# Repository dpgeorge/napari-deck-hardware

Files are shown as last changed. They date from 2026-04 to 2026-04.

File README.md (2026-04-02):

Napari Deck Hardware
====================

The Napari Deck is a custom keyboard-like USB HID input device with keys,
sliders, encoders and trackpads.  It is optimised for controlling [napari],
a multi-dimensional image viewer.

This repository contains the hardware design files needed to build a Napari
Deck: parts lists, 3D printed housing files and PCB design files.

Deck v1
-------

Napari Deck v1 is the first iteration of the housing and inputs (encoders, sliders,
buttons).  It is used to evaluate the inputs and the general layout of the deck.

It has the following inputs:
- mini trackball at the thumb position
- two keyboard switches
- two encoders
- iPod-like dial with encoder and five buttons
- mini joystick
- a slider (linear potentiometer)

Deck v2
-------

Napari Deck v2 is the second iteration of the housing and inputs, and is a fully
functional USB HID device that works with napari using `napari-deck-plugin`.

It has the following inputs:
- mini joystick at the thumb position for 3D rotation
- mini trackball at the thumb position for panning
- two encoders at the thumb position for rotation and zoom
- 16 keyboard switches
- three encoders for 3-axis slicing
- two sliders for opacity and brush size
- two sliders combined with a selection switch for four clipping planes

Deck mini
---------

Napari Deck Mini is a small device used to evaluate a mini trackpad and an encoder.
It is fully functional and works with napari.

It has the following inputs:
- mini trackpad
- encoder

Deck v3
-------

Napari Deck v3 is the third iteration of the housing and inputs.  It has a custom
PCB to simplify the construction, with a built-in STM32G0B1 microcontroller.

It has the following inputs:
- two mini trackpads at the thumb position for 2D panning and 3D rotation
- two encoders at the thumb position for zoom and 3D rotation
- 16 keyboard switches
- three encoders for 3-axis slicing
- two sliders for opacity and brush size
- two sliders combined with a 4-way selection switch for eight clipping planes

Deck v3 is currently a work-in-progress.

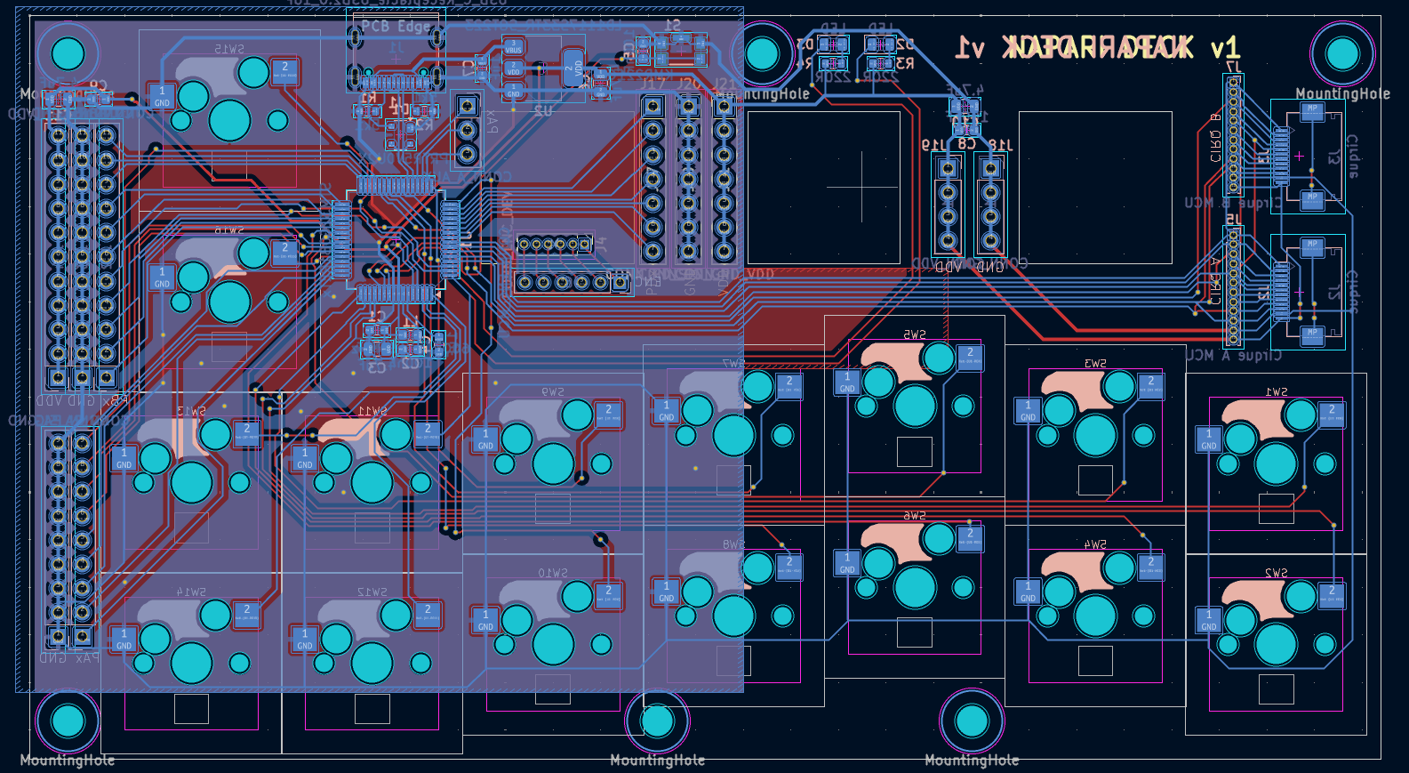
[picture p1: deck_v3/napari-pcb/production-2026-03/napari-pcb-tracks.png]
KiCad track layout for deck v3


[napari]: https://github.com/napari/napari

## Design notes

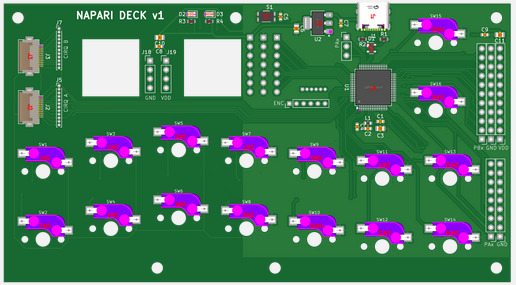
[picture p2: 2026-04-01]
deck_v3/napari-pcb/production-2026-03/napari-pcb-jlcpcb-model.jpg

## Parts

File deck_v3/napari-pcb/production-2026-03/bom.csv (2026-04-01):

Designator | Footprint | Quantity | Value | LCSC Part #
C1, C2, C5, C8, C9 | 0603 | 5 | 100nF | C14663
C10, C11, C3, C6 | 0805 | 4 | 4.7uF | C1779
C4, C7 | 0603 | 2 | 1uF | C15849
D1 | SOT-143 | 1 | PRTR5V0U2X | C2827688
D2 | 0805 | 1 | LED | C84256
D3 | 0805 | 1 | LED | C2297
J1 | USB_C_Receptacle_Palconn_UTC16-G | 1 | USB_C_Receptacle_USB2.0_16P | C165948
J2, J3 | Hirose_FH12-12S-0.5SH_1x12-1MP_P0.50mm_Horizontal | 2 | Cirque | C88360
L1 | 0603 | 1 | 600R @ 100MHz | C1002
R1, R2 | 0603 | 2 | 5k1 | C23186
R3, R4 | 0603 | 2 | 220R | C22962
S1 | SW_KMR221GLFS | 1 | KMR221GLFS | C72443
SW1, SW10, SW11, SW12, SW13, SW14, SW15, SW16, SW2, SW3, SW4, SW5, SW6, SW7, SW8, SW9 | keyswitch_cherrymx_hotswap_1u | 16 | SW_Push | C41430893
U1 | LQFP-64_10x10mm_P0.5mm | 1 | STM32G0B1RETx | C2829307
U2 | SOT-223-3_TabPin2 | 1 | LD1117S33TR_SOT223 | C435835

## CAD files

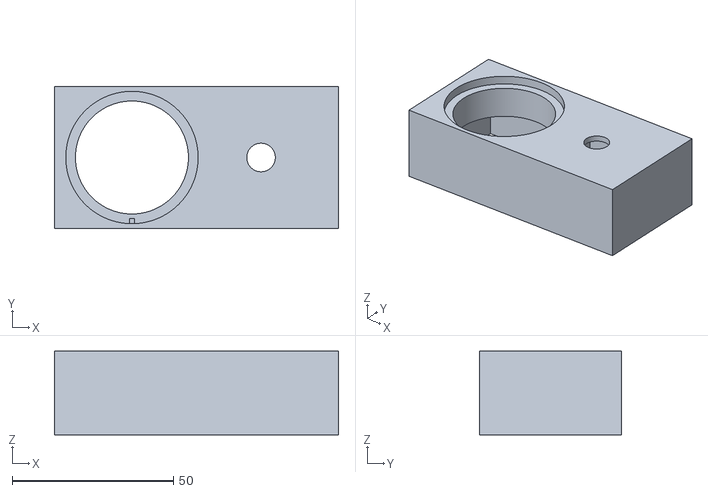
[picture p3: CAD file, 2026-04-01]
deck_mini/napari_mini.stl
88.0 x 44.0 x 26.0

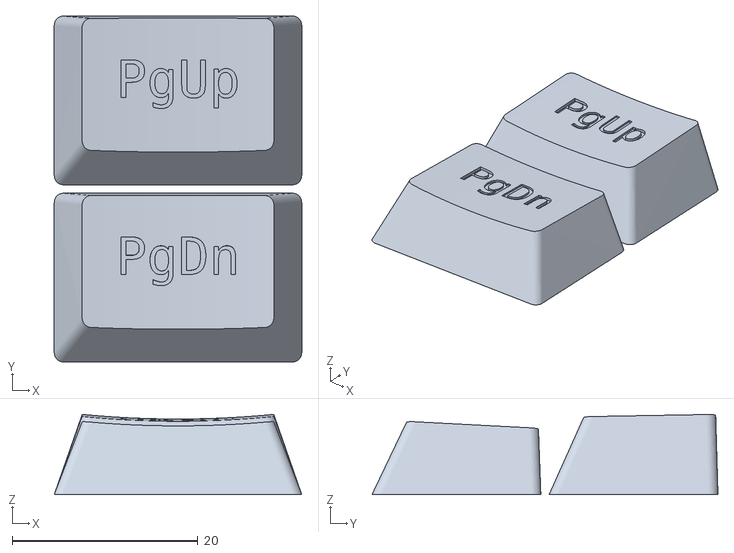
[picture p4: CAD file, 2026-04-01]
keycaps/pgup_pgdn_u1p444.stl
26.6 x 37.2 x 8.61

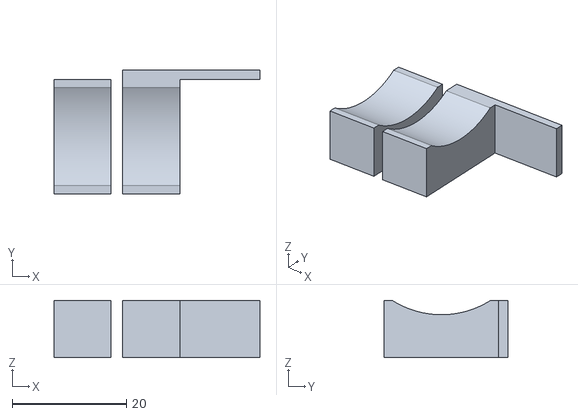
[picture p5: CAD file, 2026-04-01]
keycaps/keycaps_slider.stl
36.0 x 21.6 x 10.0

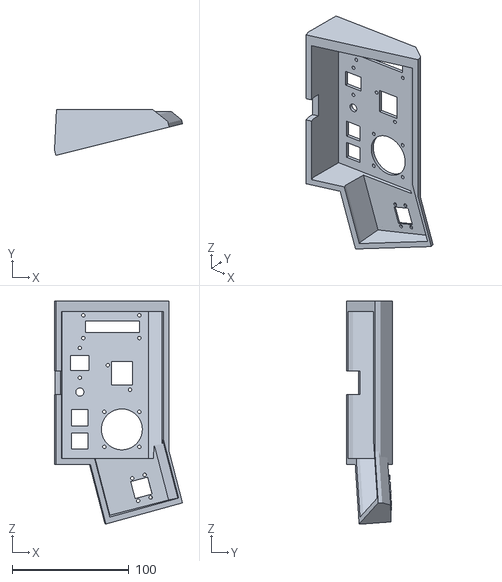
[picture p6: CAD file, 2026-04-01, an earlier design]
deck_v1/napari_v1.stl
109.7 x 39.3 x 191.1

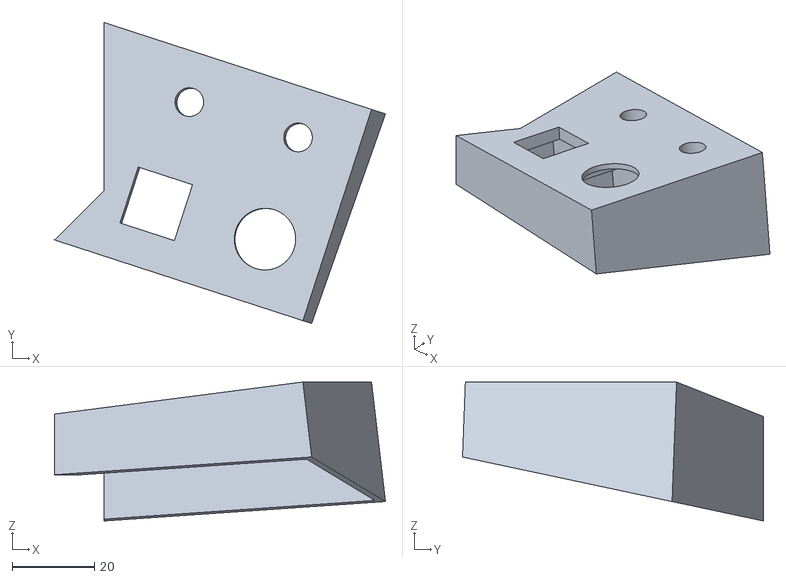
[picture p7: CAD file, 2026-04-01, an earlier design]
deck_v2/napari_v2_right.stl
80.5 x 73.2 x 33.8

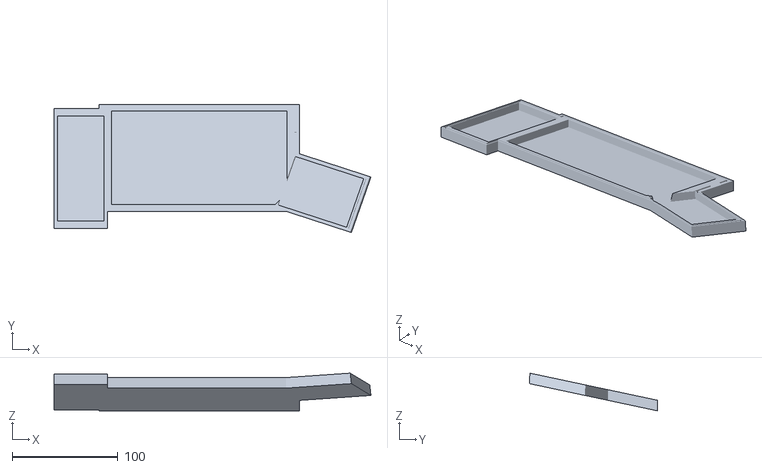
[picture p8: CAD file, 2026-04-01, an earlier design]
deck_v2/napari_v2_base_thick.stl
299.6 x 121.1 x 35.7

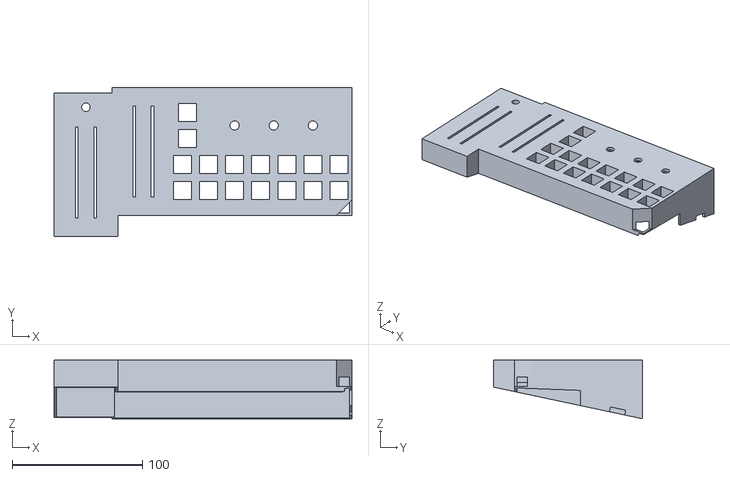
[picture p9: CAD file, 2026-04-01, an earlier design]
deck_v2/napari_v2_centre.stl
228.5 x 114.0 x 44.9

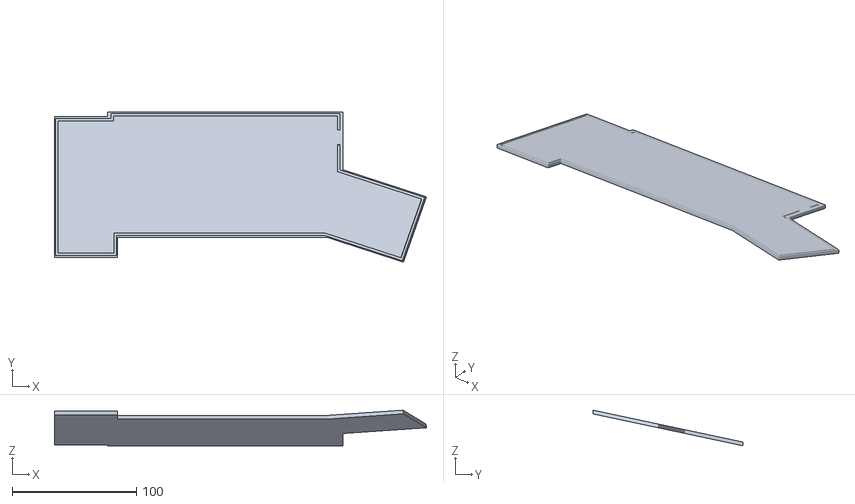
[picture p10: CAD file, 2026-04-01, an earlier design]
deck_v2/napari_v2_base_thin.stl
298.9 x 120.8 x 28.7

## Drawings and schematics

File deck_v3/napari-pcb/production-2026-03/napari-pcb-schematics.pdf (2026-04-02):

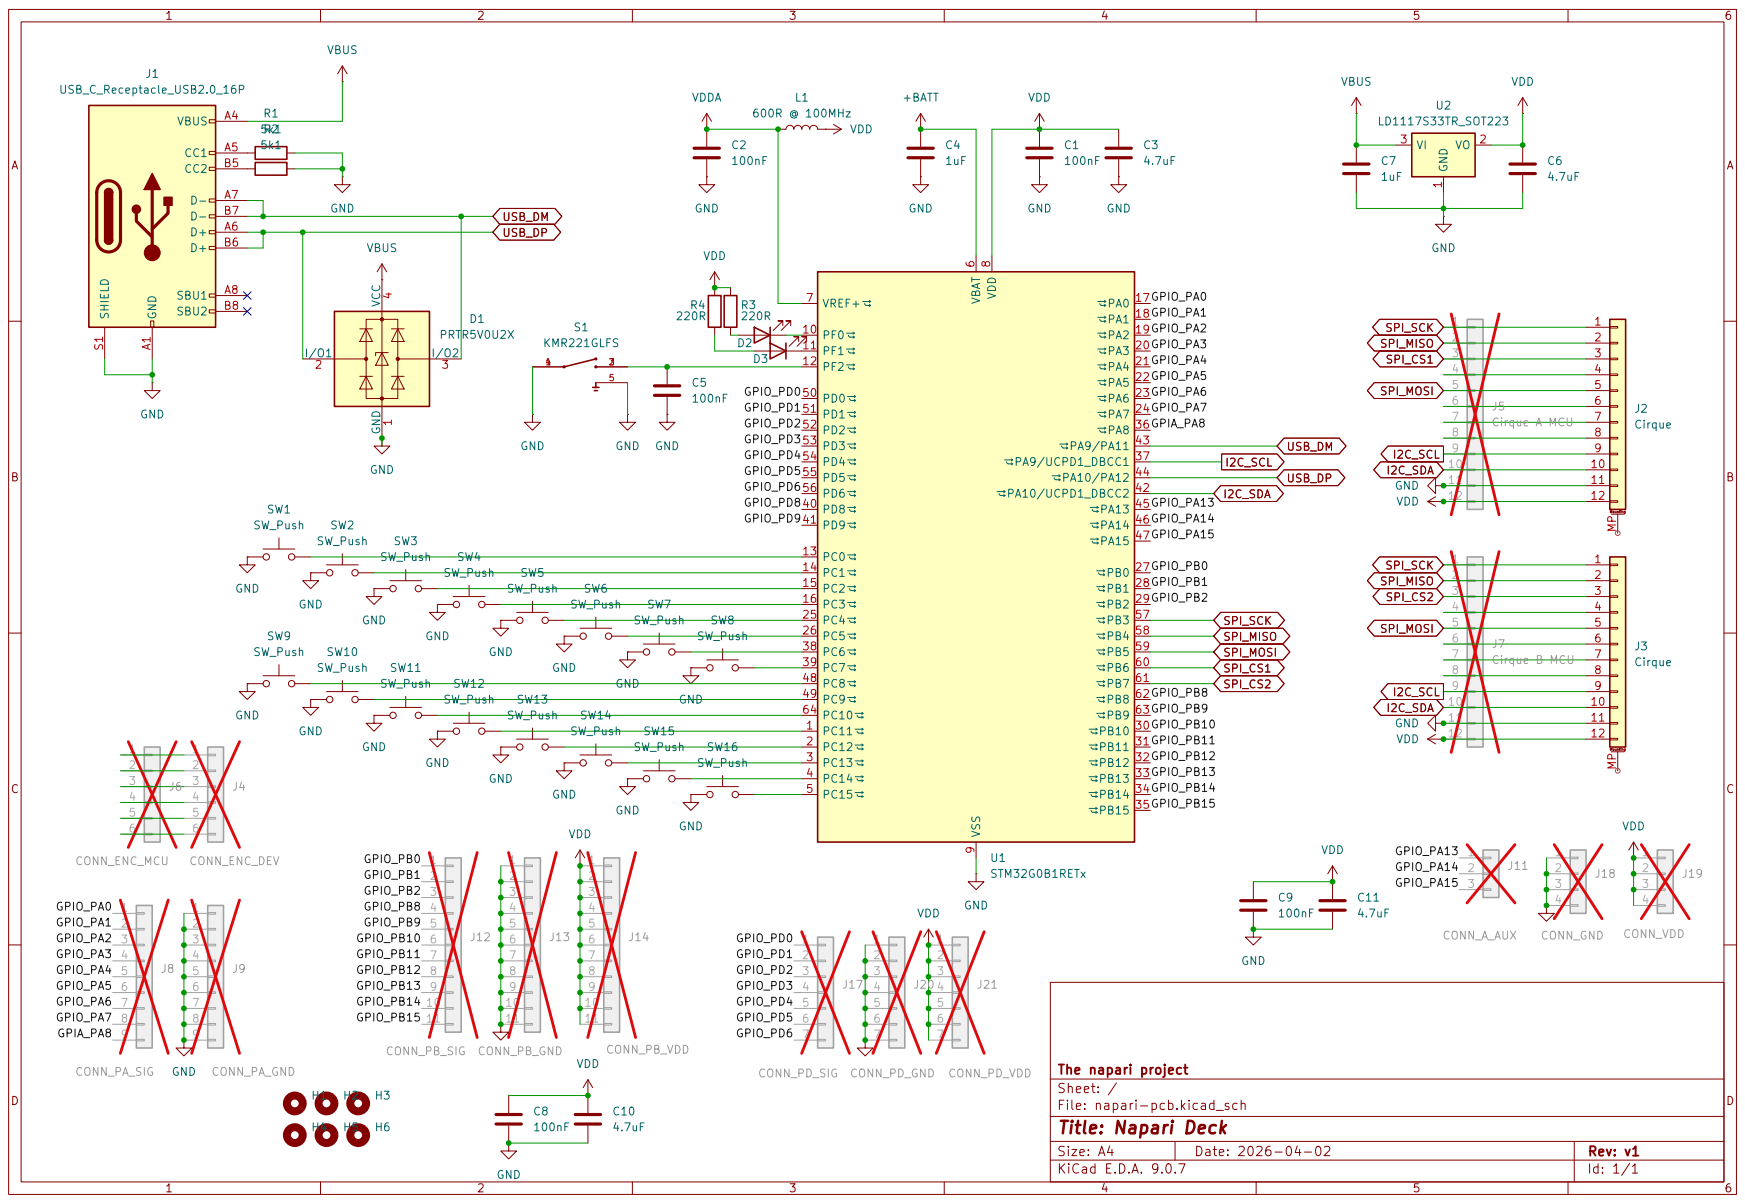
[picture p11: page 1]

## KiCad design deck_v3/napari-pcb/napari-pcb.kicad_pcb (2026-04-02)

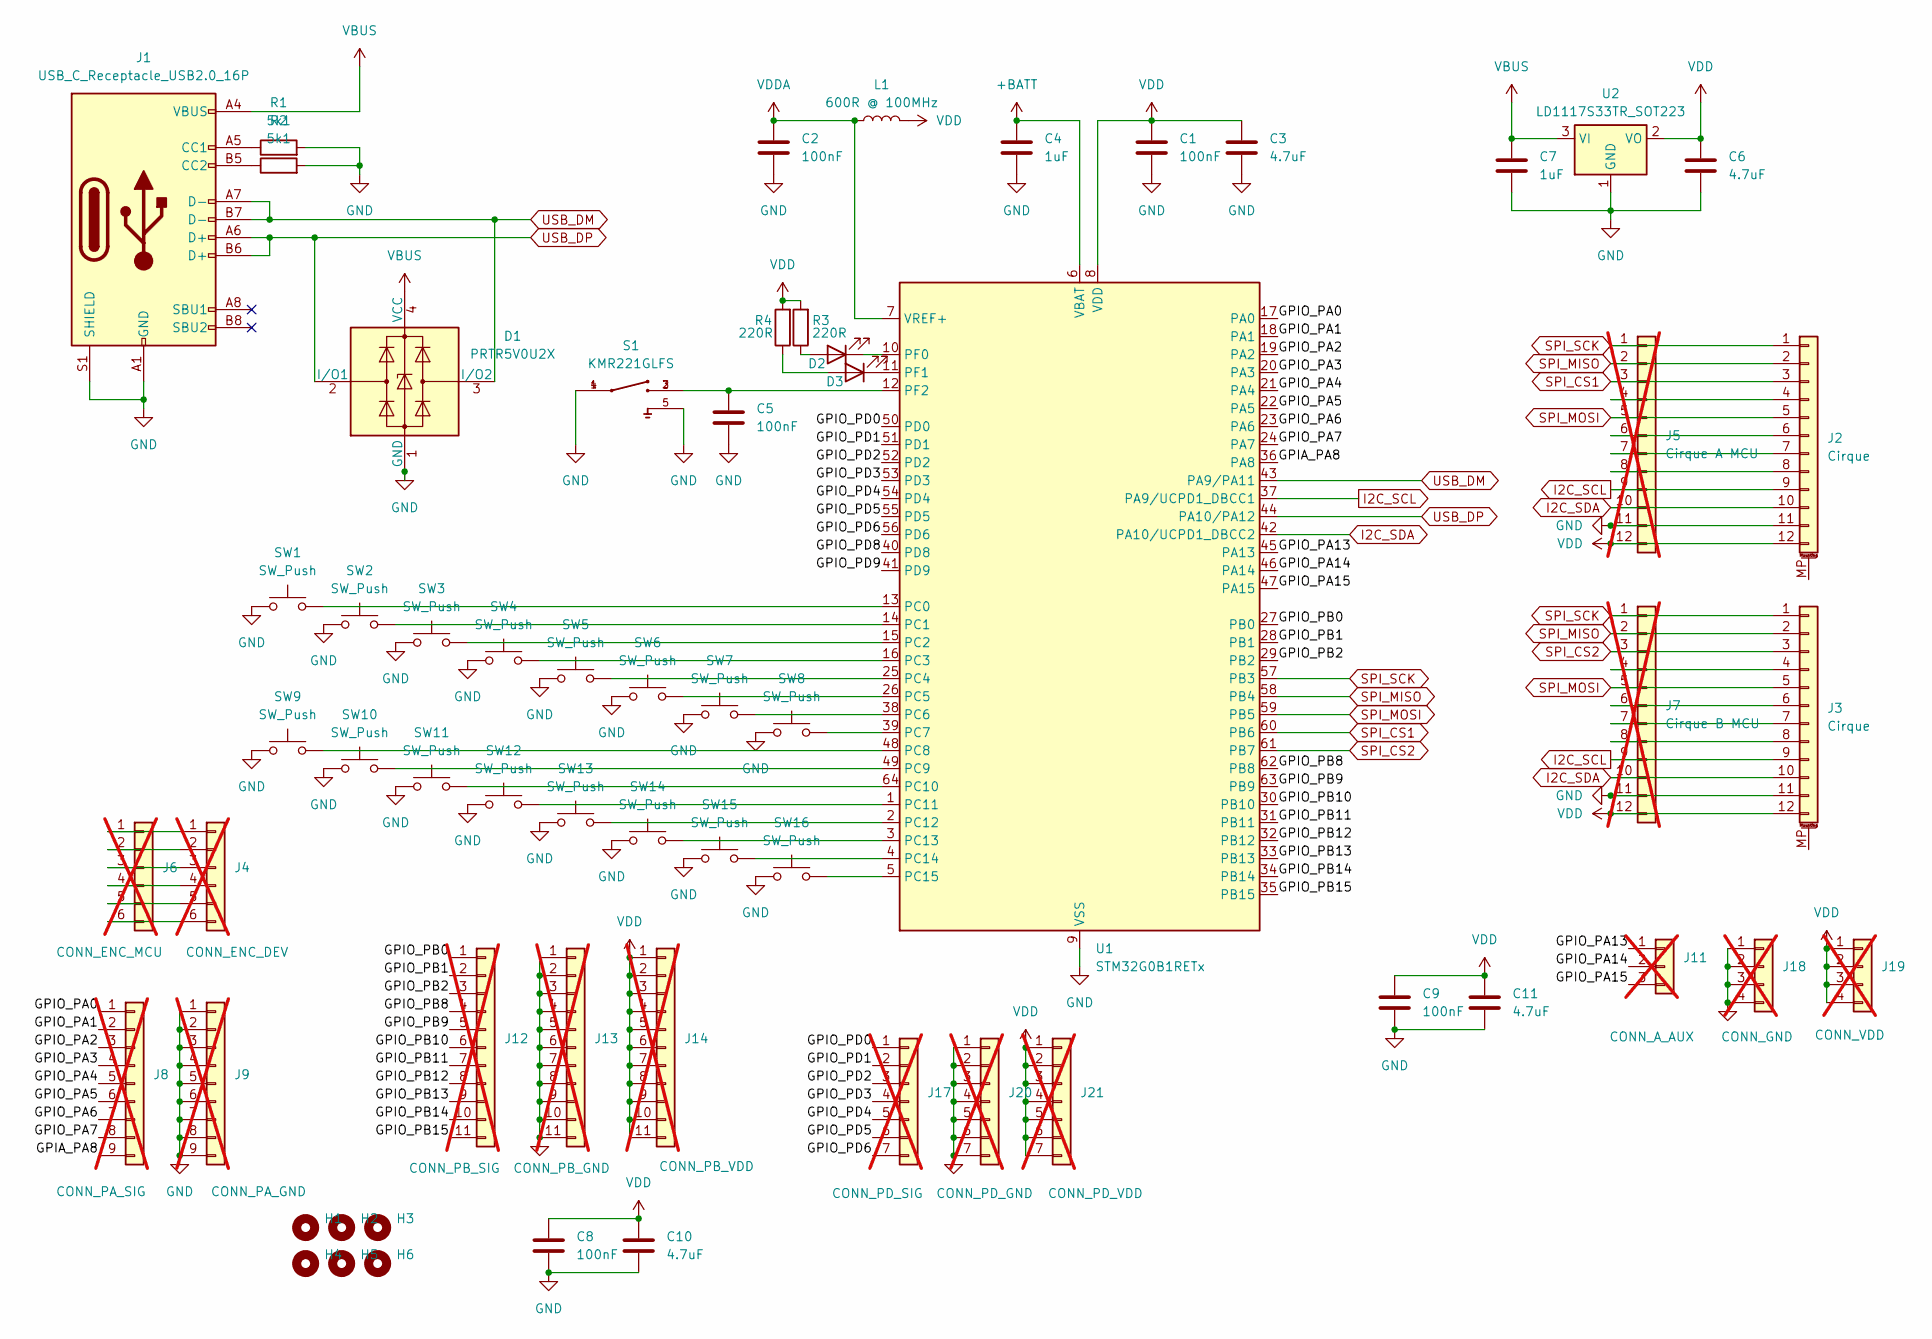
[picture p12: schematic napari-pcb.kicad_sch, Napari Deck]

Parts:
C1, C2, C5, C8, C9: 100nF; C_0603_1608Metric; LCSC Part # C14663
C3, C6, C10, C11: 4.7uF; C_0805_2012Metric; LCSC Part # C1779
C4, C7: 1uF; C_0603_1608Metric; LCSC Part # C15849
D1: PRTR5V0U2X; SOT-143; LCSC Part # C2827688
D2: LED; LED_0805_2012Metric; LCSC Part # C84256
D3: LED; LED_0805_2012Metric; LCSC Part # C2297
H1, H2, H3, H4, H5, H6: MountingHole; MountingHole_3.2mm_M3
J1: USB_C_Receptacle_USB2.0_16P; USB_C_Receptacle_Palconn_UTC16-G; LCSC Part # C165948
J2, J3: Cirque; Hirose_FH12-12S-0.5SH_1x12-1MP_P0.50mm_Horizontal; LCSC Part # C88360
J4: CONN_ENC_DEV; PinHeader_1x06_P1.27mm_Vertical; not fitted
J5: Cirque A MCU; PinHeader_1x12_P1.00mm_Vertical; not fitted
J6: CONN_ENC_MCU; PinHeader_1x06_P2.00mm_Vertical; not fitted
J7: Cirque B MCU; PinHeader_1x12_P1.00mm_Vertical; not fitted
J8: CONN_PA_SIG; PinHeader_1x09_P2.54mm_Vertical; not fitted
J9: CONN_PA_GND; PinHeader_1x09_P2.54mm_Vertical; not fitted
J11: CONN_A_AUX; PinHeader_1x03_P2.54mm_Vertical; not fitted
J12: CONN_PB_SIG; PinHeader_1x11_P2.54mm_Vertical; not fitted
J13: CONN_PB_GND; PinHeader_1x11_P2.54mm_Vertical; not fitted
J14: CONN_PB_VDD; PinHeader_1x11_P2.54mm_Vertical; not fitted
J17: CONN_PD_SIG; PinHeader_1x07_P2.54mm_Vertical; not fitted
J18: CONN_GND; PinHeader_1x04_P2.54mm_Vertical; not fitted
J19: CONN_VDD; PinHeader_1x04_P2.54mm_Vertical; not fitted
J20: CONN_PD_GND; PinHeader_1x07_P2.54mm_Vertical; not fitted
J21: CONN_PD_VDD; PinHeader_1x07_P2.54mm_Vertical; not fitted
L1: 600R @ 100MHz; L_0603_1608Metric; LCSC Part # C1002
R1, R2: 5k1; R_0603_1608Metric; LCSC Part # C23186
R3, R4: 220R; R_0603_1608Metric; LCSC Part # C22962
S1: KMR221GLFS; SW_KMR221GLFS; LCSC Part # C72443
SW1, SW2, SW3, SW4, SW5, SW6, SW7, SW8, SW9, SW10, SW11, SW12, SW13, SW14, SW15, SW16: SW_Push; keyswitch_cherrymx_hotswap_1u; LCSC Part # C41430893
U1: STM32G0B1RETx; LQFP-64_10x10mm_P0.5mm; LCSC Part # C2829307
U2: LD1117S33TR_SOT223; SOT-223-3_TabPin2; LCSC Part # C435835

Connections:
+BATT: C4.1, U1.6 (VBAT)
/GPIA_PA8: J8.9, U1.36 (PA8)
/GPIO_PA0: J8.1, U1.17 (PA0)
/GPIO_PA1: J8.2, U1.18 (PA1)
/GPIO_PA2: J8.3, U1.19 (PA2)
/GPIO_PA3: J8.4, U1.20 (PA3)
/GPIO_PA4: J8.5, U1.21 (PA4)
/GPIO_PA5: J8.6, U1.22 (PA5)
/GPIO_PA6: J8.7, U1.23 (PA6)
/GPIO_PA7: J8.8, U1.24 (PA7)
/GPIO_PA13: J11.1, U1.45 (PA13)
/GPIO_PA14: J11.2, U1.46 (PA14)
/GPIO_PA15: J11.3, U1.47 (PA15)
/GPIO_PB0: J12.1, U1.27 (PB0)
/GPIO_PB1: J12.2, U1.28 (PB1)
/GPIO_PB2: J12.3, U1.29 (PB2)
/GPIO_PB8: J12.4, U1.62 (PB8)
/GPIO_PB9: J12.5, U1.63 (PB9)
/GPIO_PB10: J12.6, U1.30 (PB10)
/GPIO_PB11: J12.7, U1.31 (PB11)
/GPIO_PB12: J12.8, U1.32 (PB12)
/GPIO_PB13: J12.9, U1.33 (PB13)
/GPIO_PB14: J12.10, U1.34 (PB14)
/GPIO_PB15: J12.11, U1.35 (PB15)
/GPIO_PD0: J17.1, U1.50 (PD0)
/GPIO_PD1: J17.2, U1.51 (PD1)
/GPIO_PD2: J17.3, U1.52 (PD2)
/GPIO_PD3: J17.4, U1.53 (PD3)
/GPIO_PD4: J17.5, U1.54 (PD4)
/GPIO_PD5: J17.6, U1.55 (PD5)
/GPIO_PD6: J17.7, U1.56 (PD6)
/GPIO_PD8: U1.40 (PD8)
/GPIO_PD9: U1.41 (PD9)
GND: C1.2, C2.2, C3.2, C4.2, C5.2, C6.2, C7.2, C8.2, C9.2, C10.2, C11.2, D1.1 (GND), J1.A1 (GND), J1.A12 (GND), J1.B1 (GND), J1.B12 (GND), J1.S1 (SHIELD), J2.11, J3.11, J5.11, J7.11, J9.1, J9.2, J9.3, J9.4, J9.5, J9.6, J9.7, J9.8, J9.9, J13.1, J13.2, J13.3, J13.4, J13.5, J13.6, J13.7, J13.8, J13.9, J13.10, J13.11, J18.1, J18.2, J18.3, J18.4, J20.1, J20.2, J20.3, J20.4, J20.5, J20.6, J20.7, R1.2, R2.2, S1.1, S1.4, S1.5, SW1.1, SW2.1, SW3.1, SW4.1, SW5.1, SW6.1, SW7.1, SW8.1, SW9.1, SW10.1, SW11.1, SW12.1, SW13.1, SW14.1, SW15.1, SW16.1, U1.9 (VSS), U2.1 (GND)
I2C_SCL: J2.9, J3.9, J5.9, J7.9, U1.37 (PA9/UCPD1_DBCC1)
I2C_SDA: J2.10, J3.10, J5.10, J7.10, U1.42 (PA10/UCPD1_DBCC2)
unnamed: D2.2 (A), R3.1
unnamed: D2.1 (K), U1.10 (PF0)
unnamed: D3.2 (A), R4.1
unnamed: D3.1 (K), U1.11 (PF1)
unnamed: J1.A5 (CC1), R1.1
unnamed: J1.B5 (CC2), R2.1
unnamed: J2.4, J5.4
unnamed: J2.6, J5.6
unnamed: J2.7, J5.7
unnamed: J2.8, J5.8
unnamed: J3.4, J7.4
unnamed: J3.6, J7.6
unnamed: J3.7, J7.7
unnamed: J3.8, J7.8
unnamed: J4.1, J6.1
unnamed: J4.2, J6.2
unnamed: J4.3, J6.3
unnamed: J4.4, J6.4
unnamed: J4.5, J6.5
unnamed: J4.6, J6.6
unnamed: SW1.2, U1.13 (PC0)
unnamed: SW2.2, U1.14 (PC1)
unnamed: SW3.2, U1.15 (PC2)
unnamed: SW4.2, U1.16 (PC3)
unnamed: SW5.2, U1.25 (PC4)
unnamed: SW6.2, U1.26 (PC5)
unnamed: SW7.2, U1.38 (PC6)
unnamed: SW8.2, U1.39 (PC7)
unnamed: SW9.2, U1.48 (PC8)
unnamed: SW10.2, U1.49 (PC9)
unnamed: SW11.2, U1.64 (PC10)
unnamed: SW12.2, U1.1 (PC11)
unnamed: SW13.2, U1.2 (PC12)
unnamed: SW14.2, U1.3 (PC13)
unnamed: SW15.2, U1.4 (PC14)
unnamed: SW16.2, U1.5 (PC15)
unnamed: C5.1, S1.2, S1.3, U1.12 (PF2)
SPI_CS1: J2.3, J5.3, U1.60 (PB6)
SPI_CS2: J3.3, J7.3, U1.61 (PB7)
SPI_MISO: J2.2, J3.2, J5.2, J7.2, U1.58 (PB4)
SPI_MOSI: J2.5, J3.5, J5.5, J7.5, U1.59 (PB5)
SPI_SCK: J2.1, J3.1, J5.1, J7.1, U1.57 (PB3)
USB_DM: D1.3 (I/O2), J1.A7 (D-), J1.B7 (D-), U1.43 (PA9/PA11)
USB_DP: D1.2 (I/O1), J1.A6 (D+), J1.B6 (D+), U1.44 (PA10/PA12)
VBUS: C7.1, D1.4 (VCC), J1.A4 (VBUS), J1.A9 (VBUS), J1.B4 (VBUS), J1.B9 (VBUS), U2.3 (VI)
VDD: C1.1, C3.1, C6.1, C8.1, C9.1, C10.1, C11.1, J2.12, J3.12, J5.12, J7.12, J14.1, J14.2, J14.3, J14.4, J14.5, J14.6, J14.7, J14.8, J14.9, J14.10, J14.11, J19.1, J19.2, J19.3, J19.4, J21.1, J21.2, J21.3, J21.4, J21.5, J21.6, J21.7, L1.2, R3.2, R4.2, U1.8 (VDD), U2.2 (VO)
VDDA: C2.1, L1.1, U1.7 (VREF+)

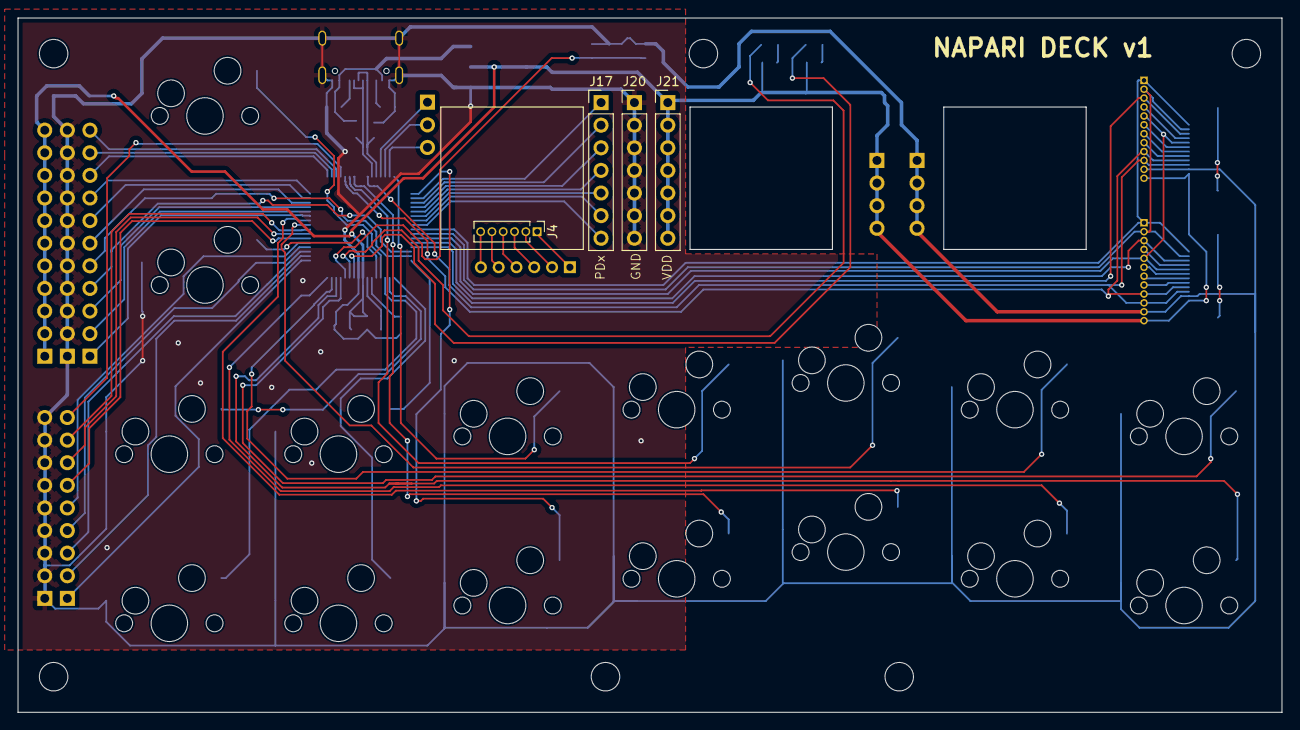
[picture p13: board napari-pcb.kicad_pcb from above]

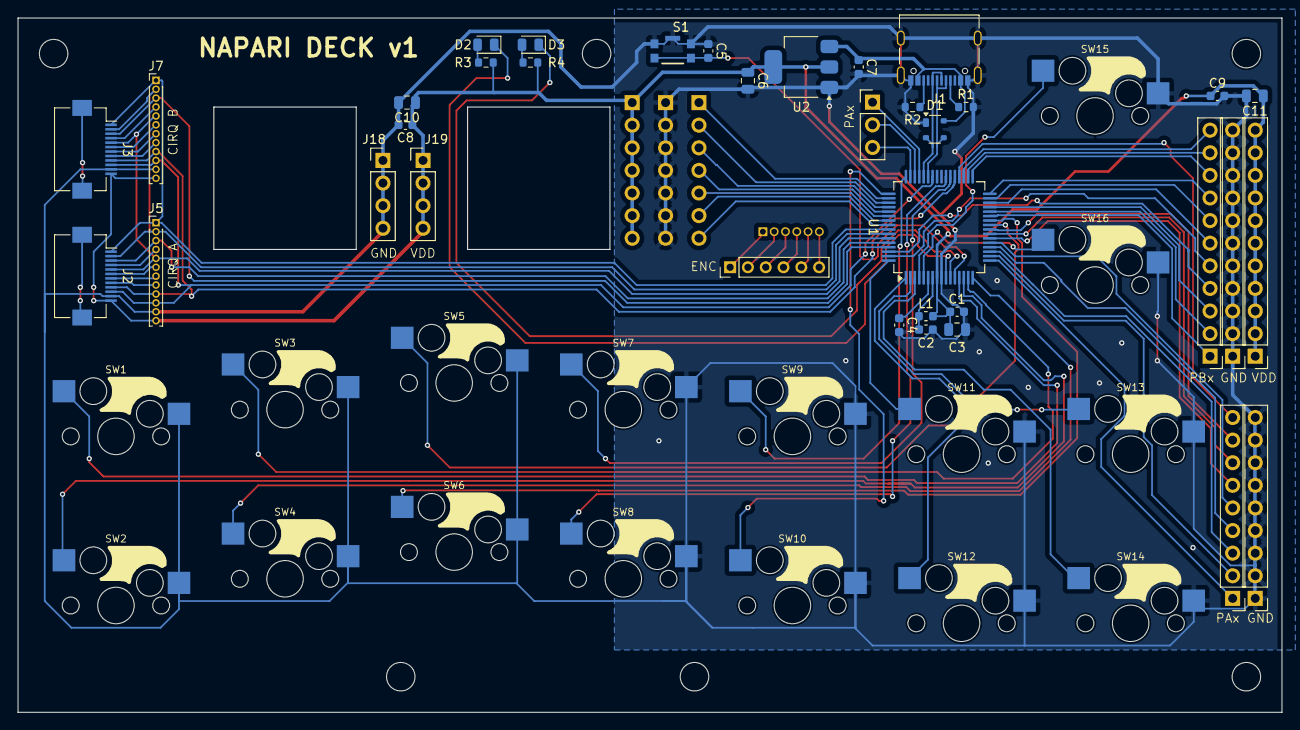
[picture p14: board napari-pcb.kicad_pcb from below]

Board: 2 copper layers, 142.0 x 78.0 mm, 62 parts (52 on the bottom side), 81 nets.

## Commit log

2026-04-01 deck_v1: Add design and output files for napari deck v1.
    [napari_v1.stl]
2026-04-01 deck_v2: Add design and output files for napari deck v2.
    [napari_v2_base_thick.stl, napari_v2_base_thin.stl, napari_v2_centre.stl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]
2026-04-01 deck_mini: Add design and output files for napari mini deck.
    [napari_mini.stl]
2026-04-01 keycaps: Add design and output files for slider keycaps.
    [keycaps_slider.stl]
2026-04-01 keycaps: Add output file for pgup/pgdn keycaps.
    Generated using https://github.com/rsheldiii/KeyV2.
    [pgup_pgdn_u1p444.stl]
2026-04-01 deck_v3: Add PCB design files for deck v3.
    [napari-pcb.kicad_pcb, napari-pcb.kicad_sch]
2026-04-01 deck_v3: Add JLCPCB production files.
    [bom.csv, designators.csv, positions.csv]
2026-04-02 deck_v3: Tweak schematic layout for improved visibility of components.
    No electrical change.
    [napari-pcb.kicad_pcb, napari-pcb.kicad_sch]
2026-04-02 deck_v3: Add schematic PDF and image of track layout for production run.
    And rename JLCPCB model image file to be consistent with the new files.
